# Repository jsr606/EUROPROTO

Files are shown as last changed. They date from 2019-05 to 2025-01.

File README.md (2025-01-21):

# EUROPROTO
an arduino / atmega platform for making digital eurorack modules and
various helper PCBs

based on on the [CHEAP, FAT and OPEN](https://vsionhairies.info/) synthesizer

## a what?
arduino based eurorack module with dual channel DAC output

kind of works :)

this is a prototyping platform. you can make modules that looks like this

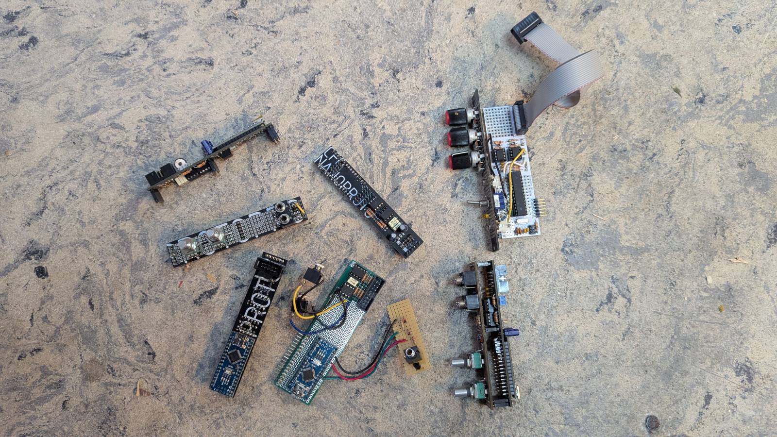
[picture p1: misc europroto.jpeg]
misc europroto.jpeg


## first version for sound days at MPLab
[workshop description and assembly guides here](/SoundDays_MPlab/README.md)

## rev3 board is here now
look in the rev3 folder. it's all old eagle stuff that i can't really open anymore, but it should possibly work?

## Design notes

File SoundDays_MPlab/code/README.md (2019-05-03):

# CFO EUROPROTO 1
# programming the module
 
the CFO EUROPROTO is based on an atmega328 chip, which is the same chip that sits at the centre of a typical arduino. this means we can program the module using the arduino software.

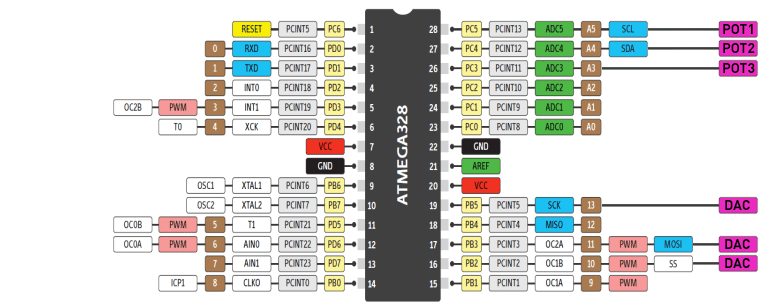
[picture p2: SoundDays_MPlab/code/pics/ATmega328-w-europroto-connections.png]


to program the module, first download the arduino IDE from https://www.arduino.cc/

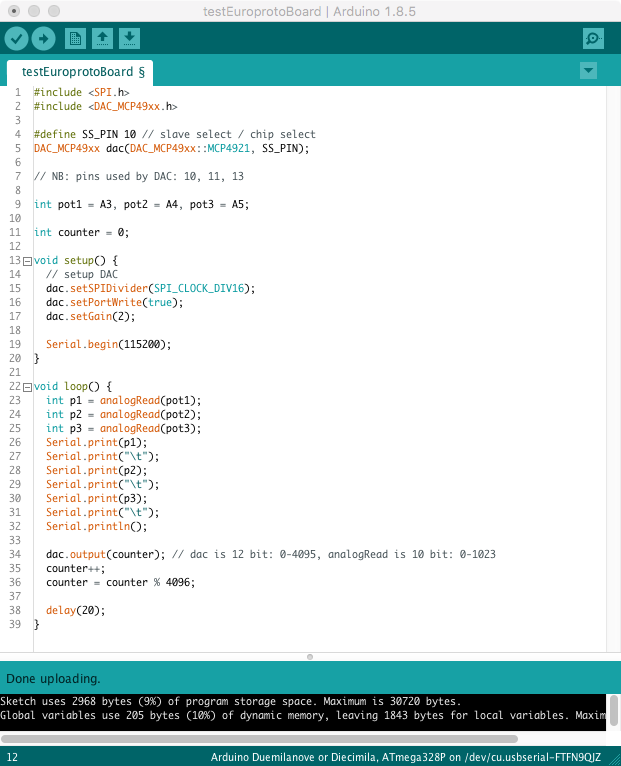
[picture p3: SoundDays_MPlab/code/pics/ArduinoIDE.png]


if you have never programmed an arduino before and need help installing the software / getting your head around microcontrollers take a look [here](https://www.arduino.cc/en/Guide/HomePage)

since the CFO EUROPROTO has no USB port, only a serial connection, you will need to use a USB to serial connecter to connect to the board.

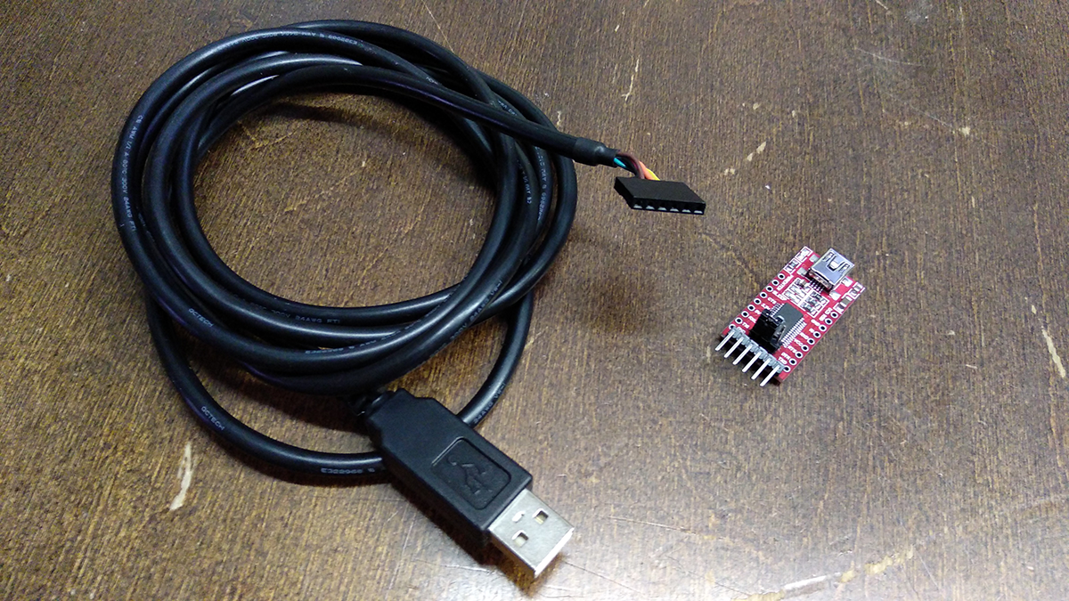
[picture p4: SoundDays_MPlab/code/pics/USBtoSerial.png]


a nice USB to serial cable [is this one](https://eu.mouser.com/ProductDetail/FTDI/TTL-234X-5V?qs=sGAEpiMZZMve4%2FbfQkoj%252BHKRsWEfBN5HUqn9pYz616g%3D), cheaper dongle style versions are [available on amazon](https://www.amazon.de/Adapter-FT232RL-Arduino-Christians-Technikshop/dp/B0178HVEH0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) too

NB: mind the orientation: GND (black wire) is down on the main board.

under tools set your arduino board to be an "arduino duemilanove and diecimila", your processor to be an "ATmega328P" and pick the USB/COM port which corresponds to you programmer (if you are unsure which it is, unplug you programmer and see which one disappears / reappears when you plug it in and out).

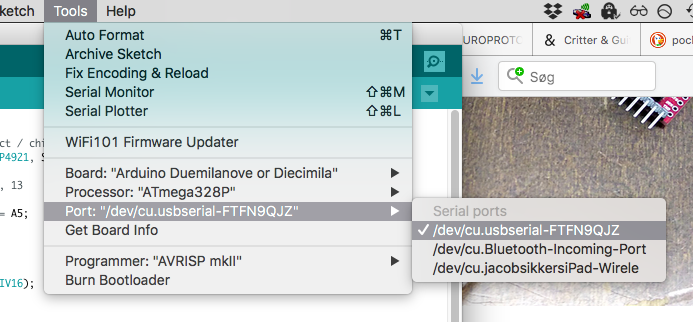
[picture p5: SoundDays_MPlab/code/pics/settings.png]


example code is in the [arduino folder](../arduino) in this repository. start with the testcode and open the serial port to see if your potentiometers are connected correctly. once this works, move on the the sound examples :)

if you would like to understand more about sound, sound synthesis, and how sound works in a computer / digital environment, i recommend reading [this processing tutorial](https://processing.org/tutorials/sound/)

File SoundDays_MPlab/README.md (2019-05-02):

# CFO EUROPROTO 1
# digital modular

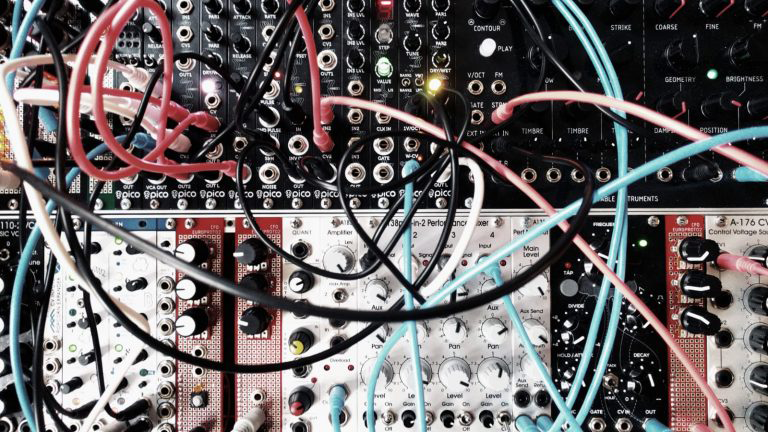
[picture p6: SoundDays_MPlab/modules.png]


workshop participants will learn to prototype simple arduino based modules that can interact with the eurorack modular world.  

programming microcontrollers in eurorack format, brings a dirty, cheap and flexible hacking approach to eurorack modular. by introducing programmable digital utility modules in the modular world we open up a pandoras box of algorithmic composition and wonderful glitches.  

the outcome of the workshop will be true hybrid modular systems that is self playing and self modulating. saturday night the workshop participants will gather for a massive common patch jam based on produced modules and doepfer a-100 system which is already available for us in mplab.  

http://sound.mplab.lv/workshops/jacob-remin/  
jacob remin, liepaja, 2-5 may 2019

## teachers

jacob remin & reinis nalivaiko

## links / references

https://vsionhairies.info/  
http://www.jacobremin.com/  
https://www.arduino.cc/  
http://sound.mplab.lv/  

## thanks!

erica synths  
https://www.ericasynths.lv/  
nordic culture point  
https://www.nordiskkulturkontakt.org  

## more infos

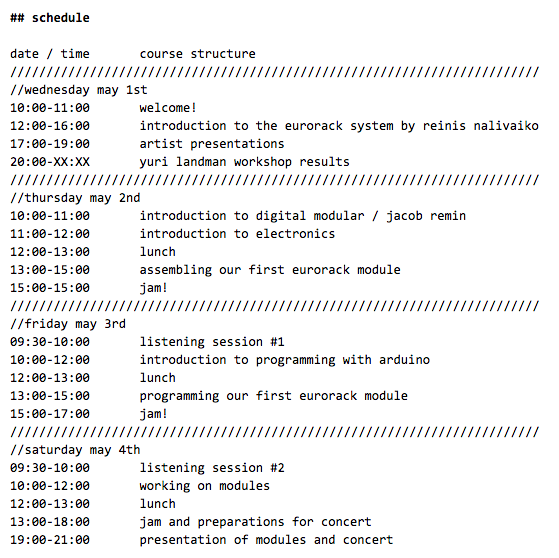
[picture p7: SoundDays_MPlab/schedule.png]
schedule
  
[build instructions](https://github.com/jsr606/EUROPROTO/tree/master/SoundDays_MPlab/build_instructions)

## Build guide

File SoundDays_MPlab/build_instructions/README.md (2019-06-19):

# CFO EUROPROTO 1
# build instructions
for digital modular workshop at MPlab sound days  
http://sound.mplab.lv/workshops/jacob-remin/  
jacob remin, liepaja, may 2019  

## BOM

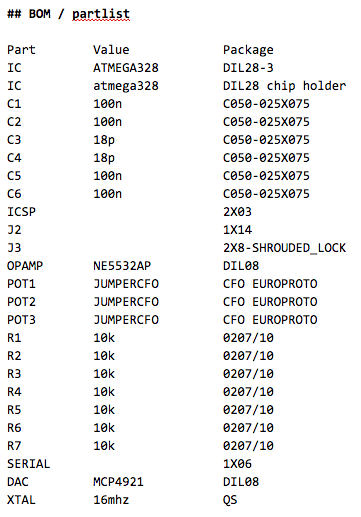
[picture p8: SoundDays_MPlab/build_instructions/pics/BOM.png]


# soldering

if you have never soldered before, i recommend looking at [this little instructional cartoon](https://blog.adafruit.com/2010/02/19/soldering-is-easy-heres-how-to-do-it-comic/)

say hello to your PCB
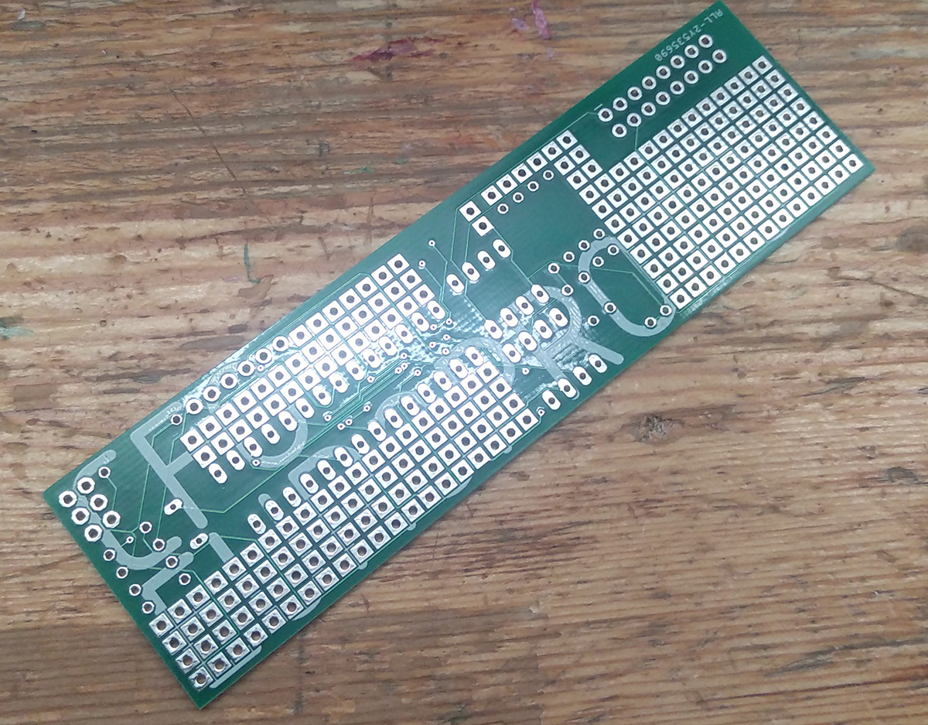
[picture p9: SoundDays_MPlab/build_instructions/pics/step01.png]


first solder the resistors. they are all 10k ohm. they have no polarity, but try to align them all the same way. just pick one. it makes it easier to see what is going on for other people (or yourself in a couple of weeeks)
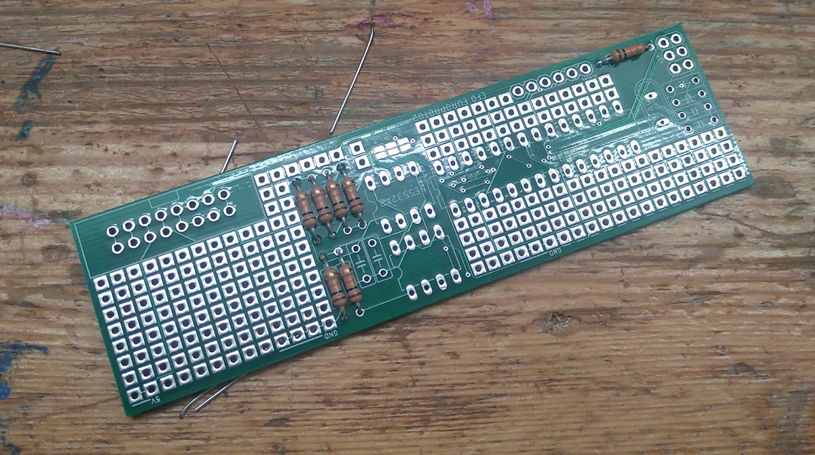
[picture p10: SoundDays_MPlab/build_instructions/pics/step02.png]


solder the 16mhz chrystal. the crystal has no polarity
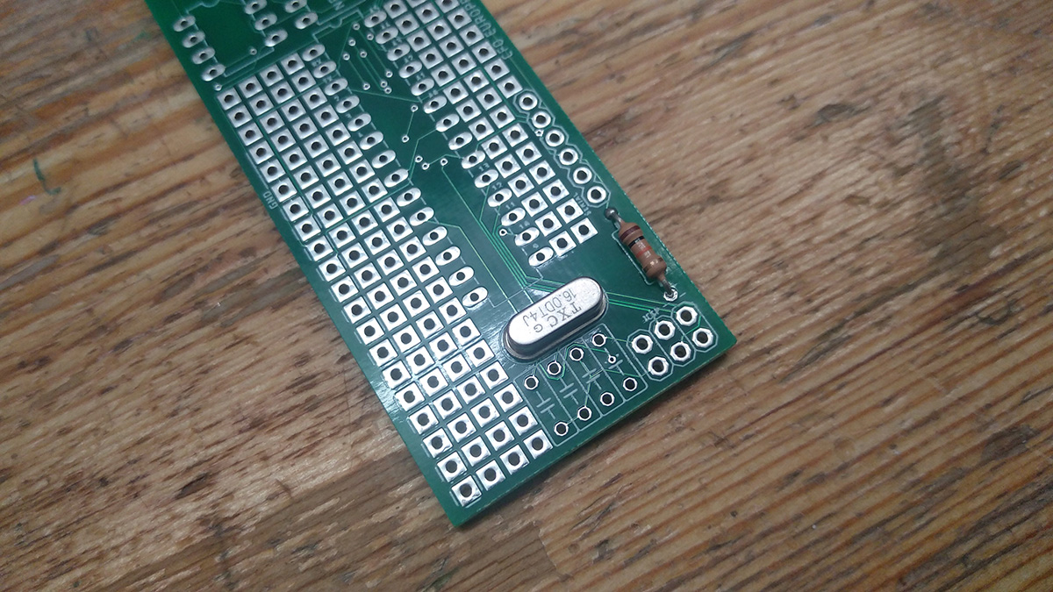
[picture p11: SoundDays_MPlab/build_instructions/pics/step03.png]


solder the 18pf capacitors. they have no polarity
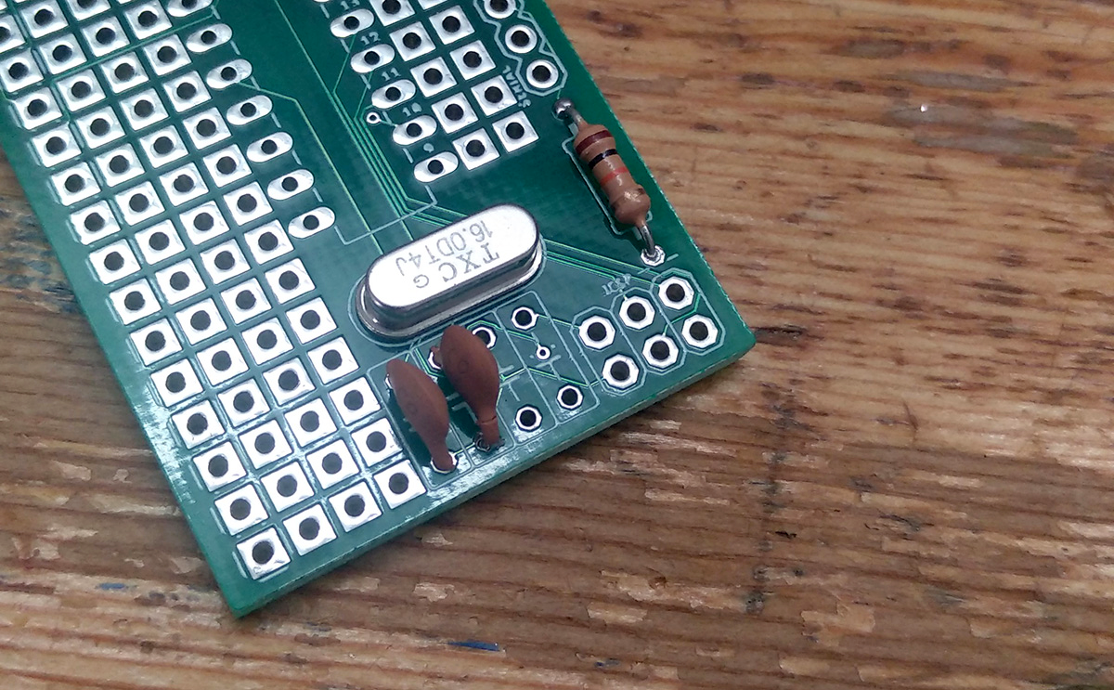
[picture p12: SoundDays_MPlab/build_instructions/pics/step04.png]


solder the 100uf capacitors. again no polarity here
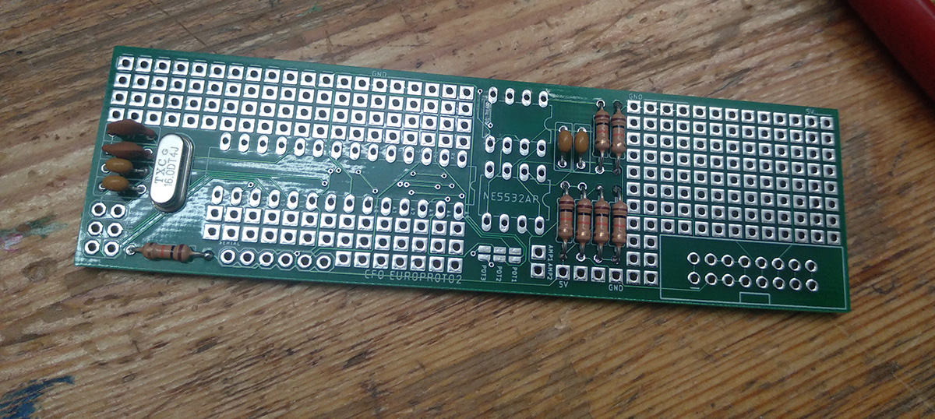
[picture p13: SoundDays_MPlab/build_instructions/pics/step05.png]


solder the IC sockets. NB: make sure to orient them correctly
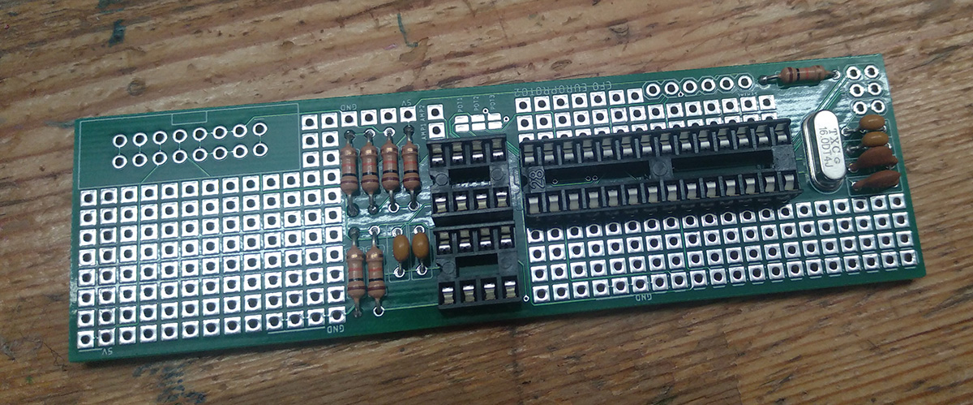
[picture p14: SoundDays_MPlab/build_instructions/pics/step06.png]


solder the programmer pin headers
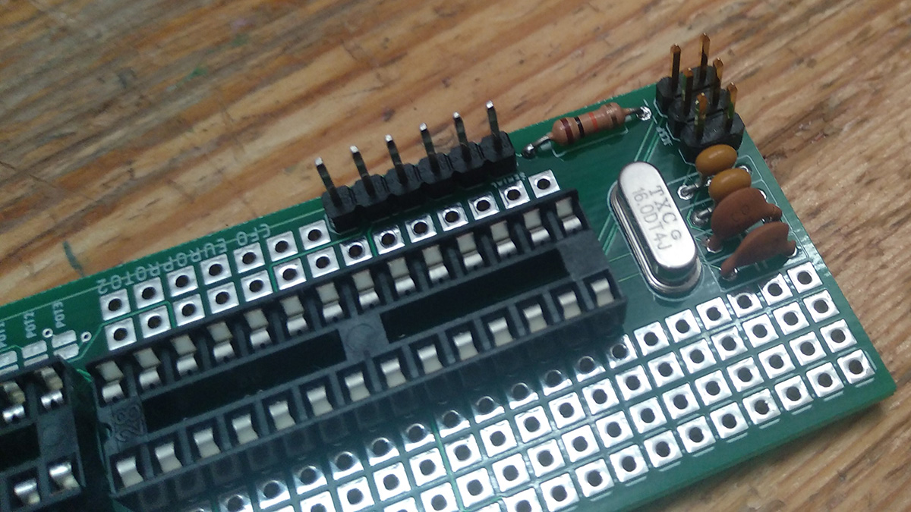
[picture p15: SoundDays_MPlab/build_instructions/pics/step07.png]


solder the power connector. for this workshop we will use 2 rows of ordinary male pin headers. to make sure they fit your eurorack power cable, connect the pin headers to the power cable while soldering them. this way they are correctly aligned
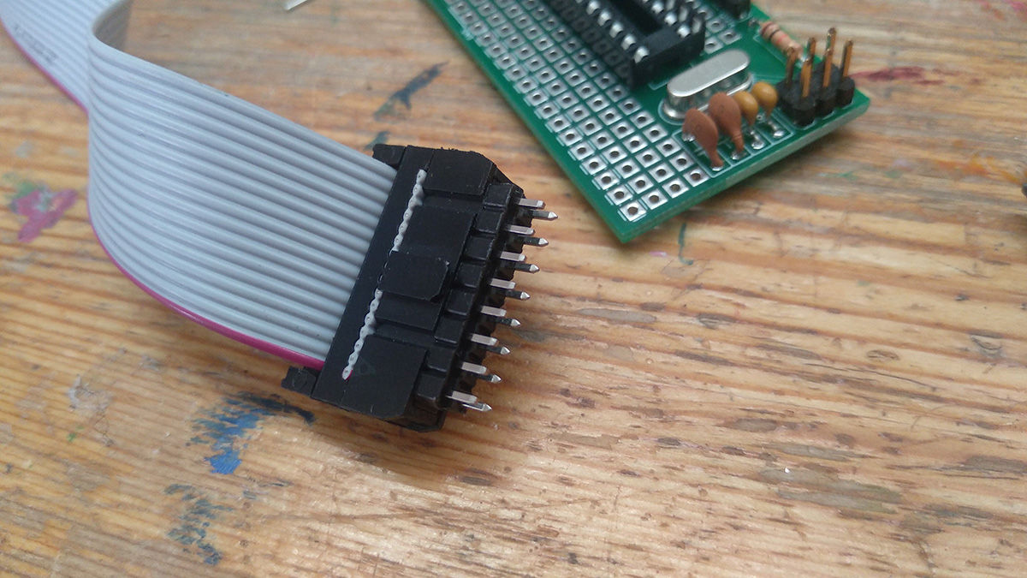
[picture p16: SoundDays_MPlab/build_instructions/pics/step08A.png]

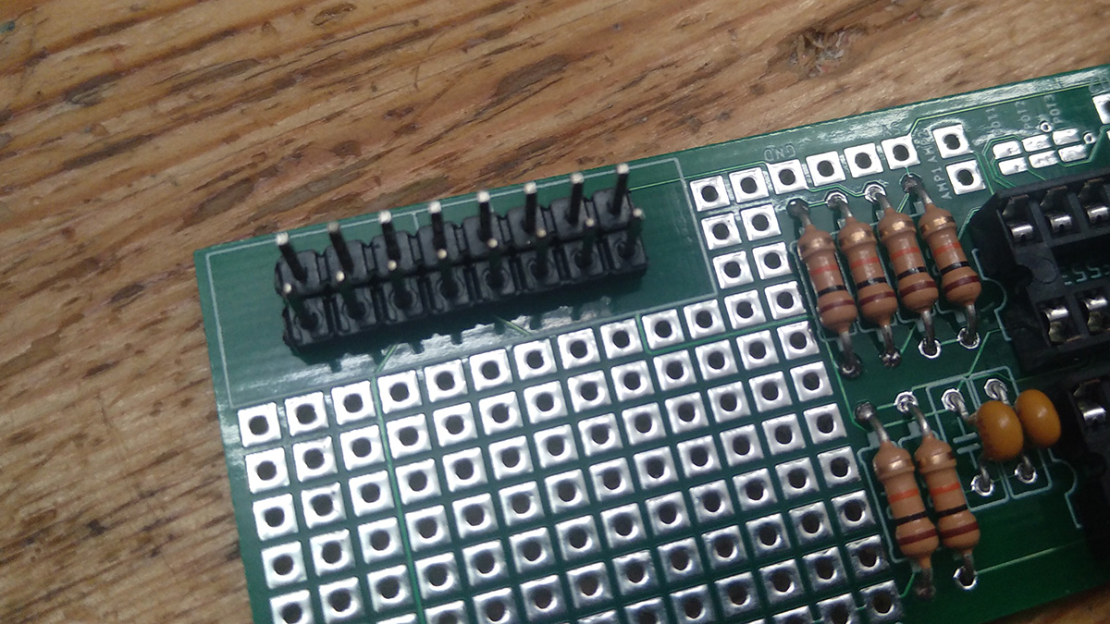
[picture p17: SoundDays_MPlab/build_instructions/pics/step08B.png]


to route the potentiometers 3 pins to the atmega328, apply solder to the 3 solder bridges marked POT1, POT2, and POT3
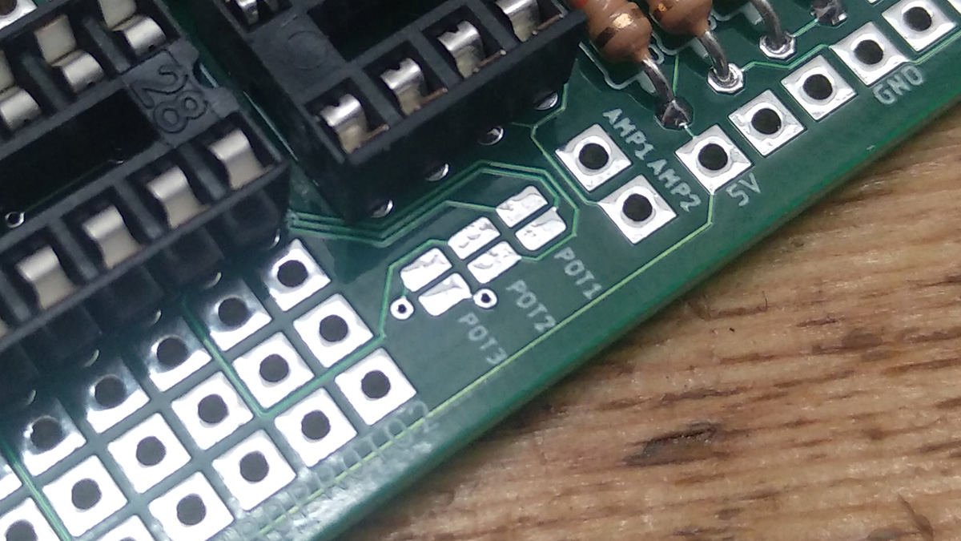
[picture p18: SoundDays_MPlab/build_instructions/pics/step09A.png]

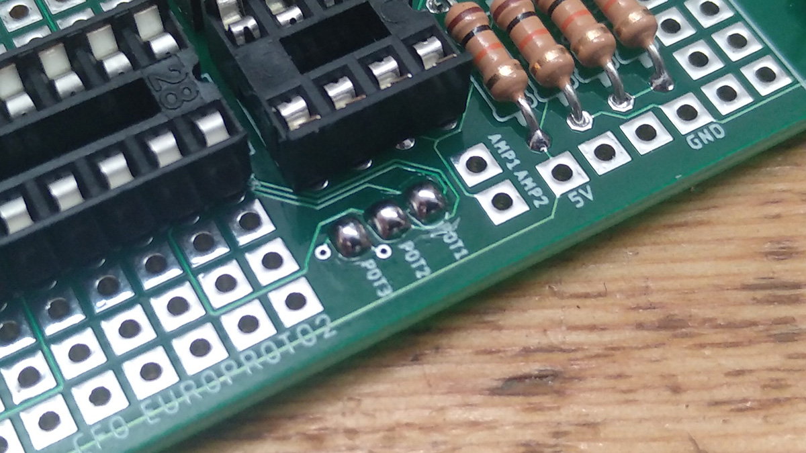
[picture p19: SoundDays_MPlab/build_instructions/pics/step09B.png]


solder the angled pin headers to the back of the PCB. NB: careful with the orientation: if you solder the pin headers to the top of the PCB your module will not fit in your synthesizer!
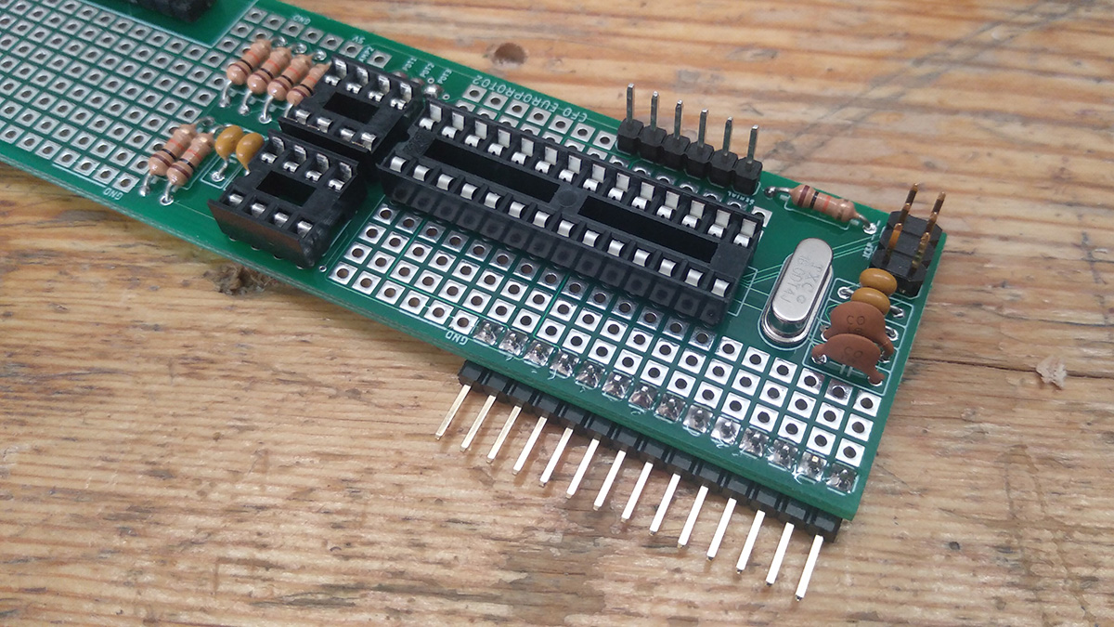
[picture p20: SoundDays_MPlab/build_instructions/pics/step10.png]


mount the ICs in the IC sockets. NB: mind the orientation of the chips, and be careful not to mix up the DAC and the opamp
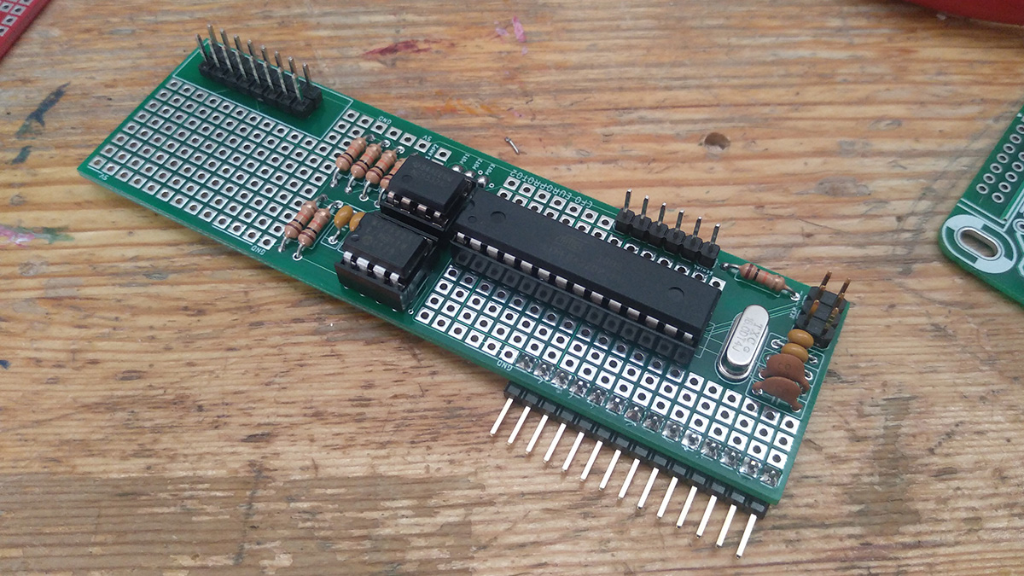
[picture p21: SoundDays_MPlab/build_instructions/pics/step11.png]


mount the ICs in the IC sockets. NB: mind the orientation of the chips, and be careful not to mix up the DAC and the opamp


that's it! you're done :) now we need to add a faceplate and program it

# faceplate

now it gets interesting! you have to decide on how many plugs your module needs. if in doubt, i suggest 3 plugs.

mark on the PCB where you want to position the plugs and drill holes :) NB: make sure you can fit the plugs and the electronics on the backside, when you solder faceplate and mainboard together. see pics below for suggested placement:

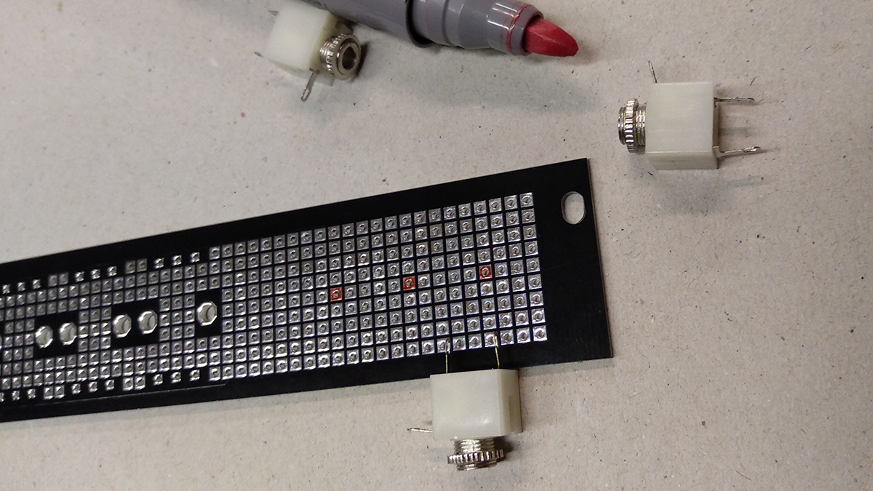
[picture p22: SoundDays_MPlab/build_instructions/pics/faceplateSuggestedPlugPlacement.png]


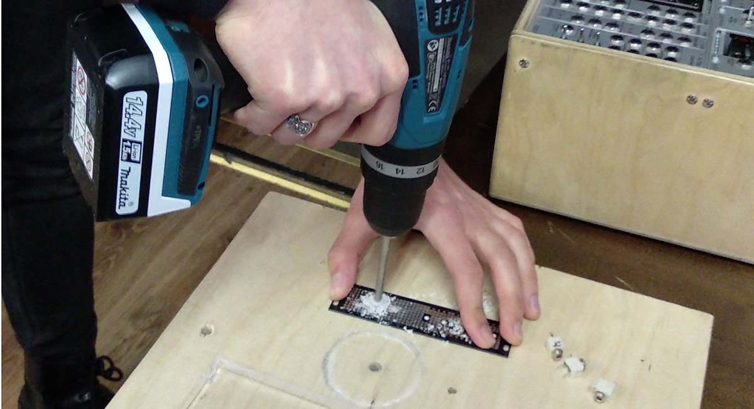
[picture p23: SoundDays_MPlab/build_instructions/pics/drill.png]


once you have the plugs mounted on the faceplate it's time to solder the potentiometers.

when connecting the faceplate to the mainboard be sure everything is aligned in a perfect 90 degree angle: solder one or two pins and calibrate before soldering all the pins. NB: if things are not straight, you module might not fit in inside your synthesizer!

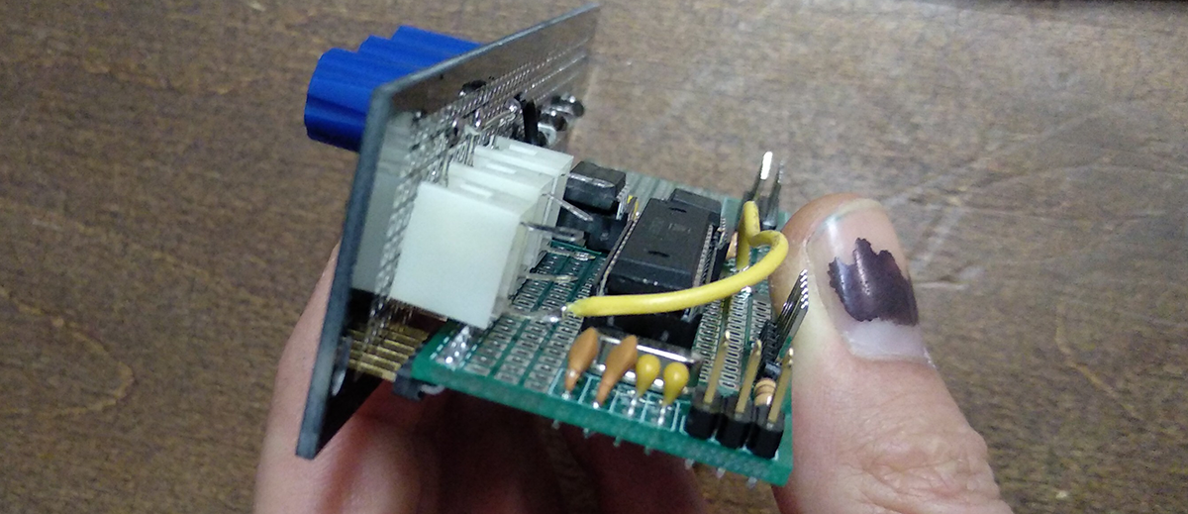
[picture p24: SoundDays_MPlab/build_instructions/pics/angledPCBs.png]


connect the ground pins of the audio jacks together. you can use wire, but might as well use some of the cut off legs from used components that you have floating around your work desk by now. 

then wire the jacks to GND on the mainboard.

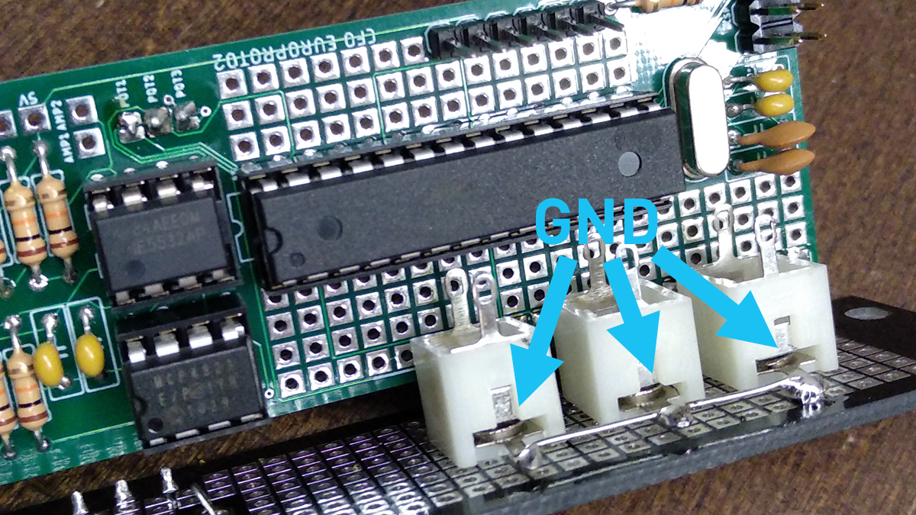
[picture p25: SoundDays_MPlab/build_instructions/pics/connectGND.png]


GND from the jacks to GND on the mainboard (could be anywhere, but see suggested connector on pic), and connect AMP1 to tip connector of the audio / CV out jack (see pic).

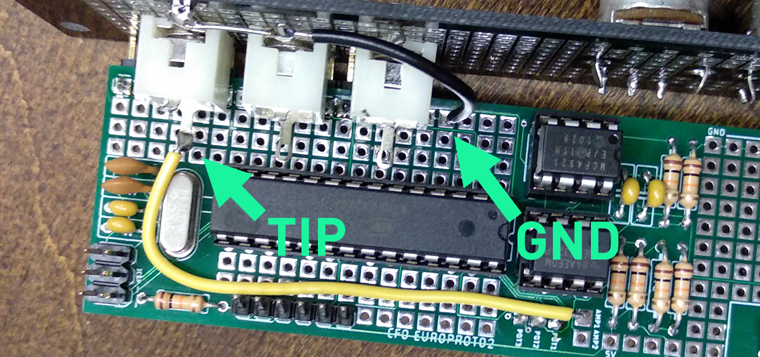
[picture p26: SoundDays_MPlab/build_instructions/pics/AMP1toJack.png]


now attach knobs to your potentiometers, and hey: well done! you've assembled your first module :)

once the module is assembled, we need to upload testcode to the chip to see if everything works. go to the [code](https://github.com/jsr606/EUROPROTO/tree/master/SoundDays_MPlab/code) part of this repository to find code examples and guidelines

# notes on output and amplification

the CFO europroto works by using a 12-bit DAC to create an analog signal between 0 and 5V (2 signals if you choose the MCP4822 DAC over the MCP4921)
this signal is the amplified to the range of -5V to 5V or 0V to 10V using the NE5532 op amp. selection between the two voltage ranges are made by applying solder to the two solder jumpers named "amp1" and "amp2". by soldering the middle pad to pad 1 a range of 0V to 10V output is selected (typical for CV applications), by soldering the middle pad to pad 2 a range of -5V to 5V is selected (typical for audio applications).

a simulation of the -5V to 5V op amp circuit can be found here: http://tinyurl.com/y3vhav76

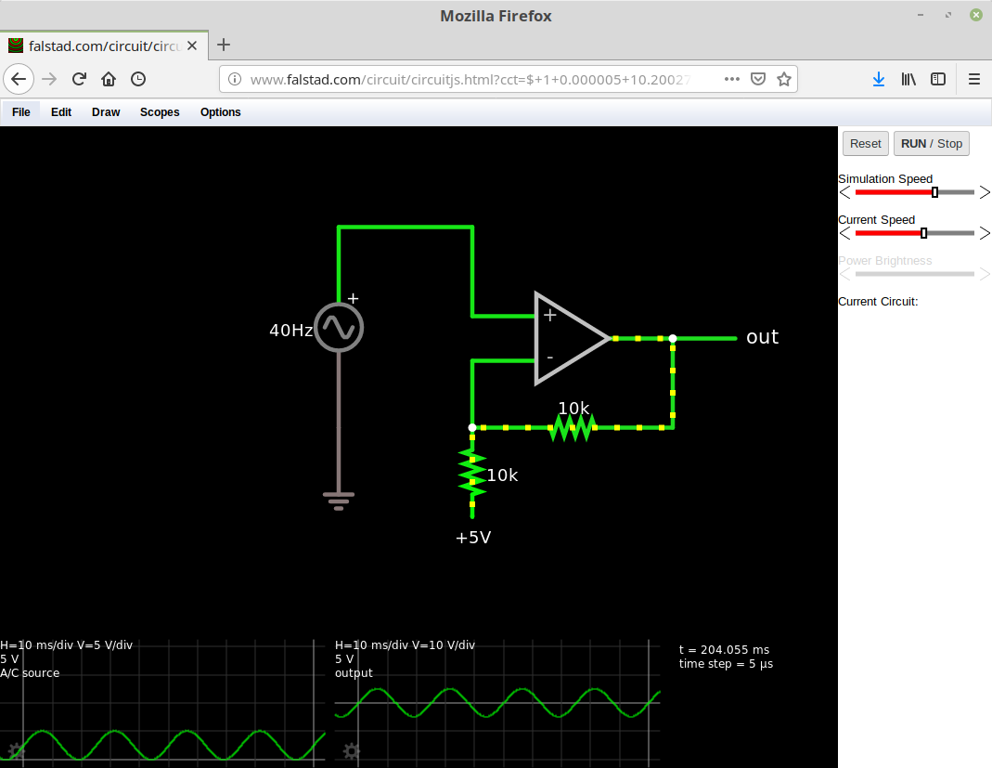
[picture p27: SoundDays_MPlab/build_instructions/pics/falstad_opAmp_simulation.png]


a simulation of the 0V to 10V op amp circuit can be found here: http://tinyurl.com/yxrvrr4l

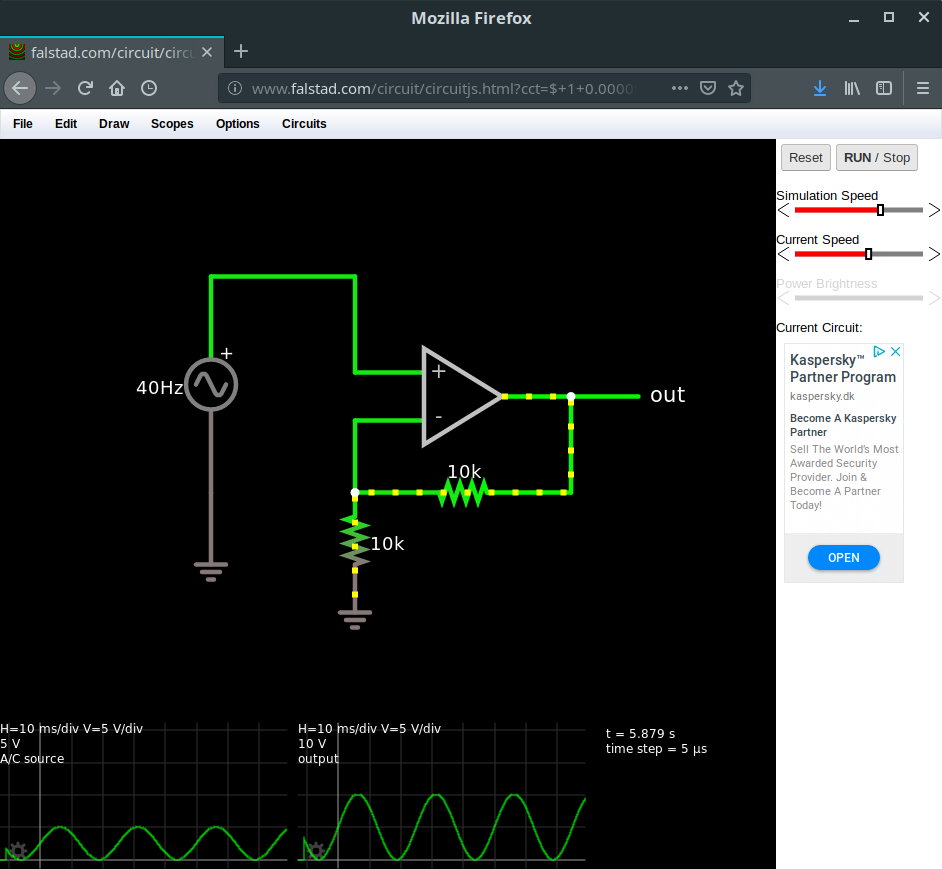
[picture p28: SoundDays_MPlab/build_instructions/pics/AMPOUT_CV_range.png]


if you are using the 1 channel DAC (MCP4921), you need to apply reference current on the VREF input of the DAC. this is conveiniently done so by soldering the solder bridge marked "VREF5V" together. if you are using the 2 channel DAC (MCP4822), the chip has internal VREF and you do NOT solder this solder bridge together.

# expansion possibilities

the following is small schematics for possible expansions, giving your module more capabilities

## CV in

use the following schematic to scale voltages from -10V to 10V to an atmega safe 0 to 5V
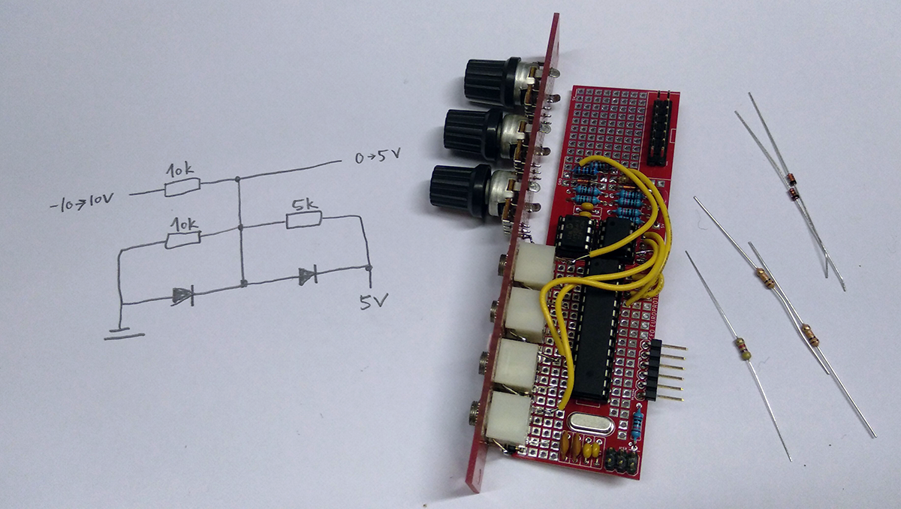
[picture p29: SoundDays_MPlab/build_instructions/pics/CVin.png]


a simulation of the CV input scaling circuit can be found here: http://tinyurl.com/y2xc58qk

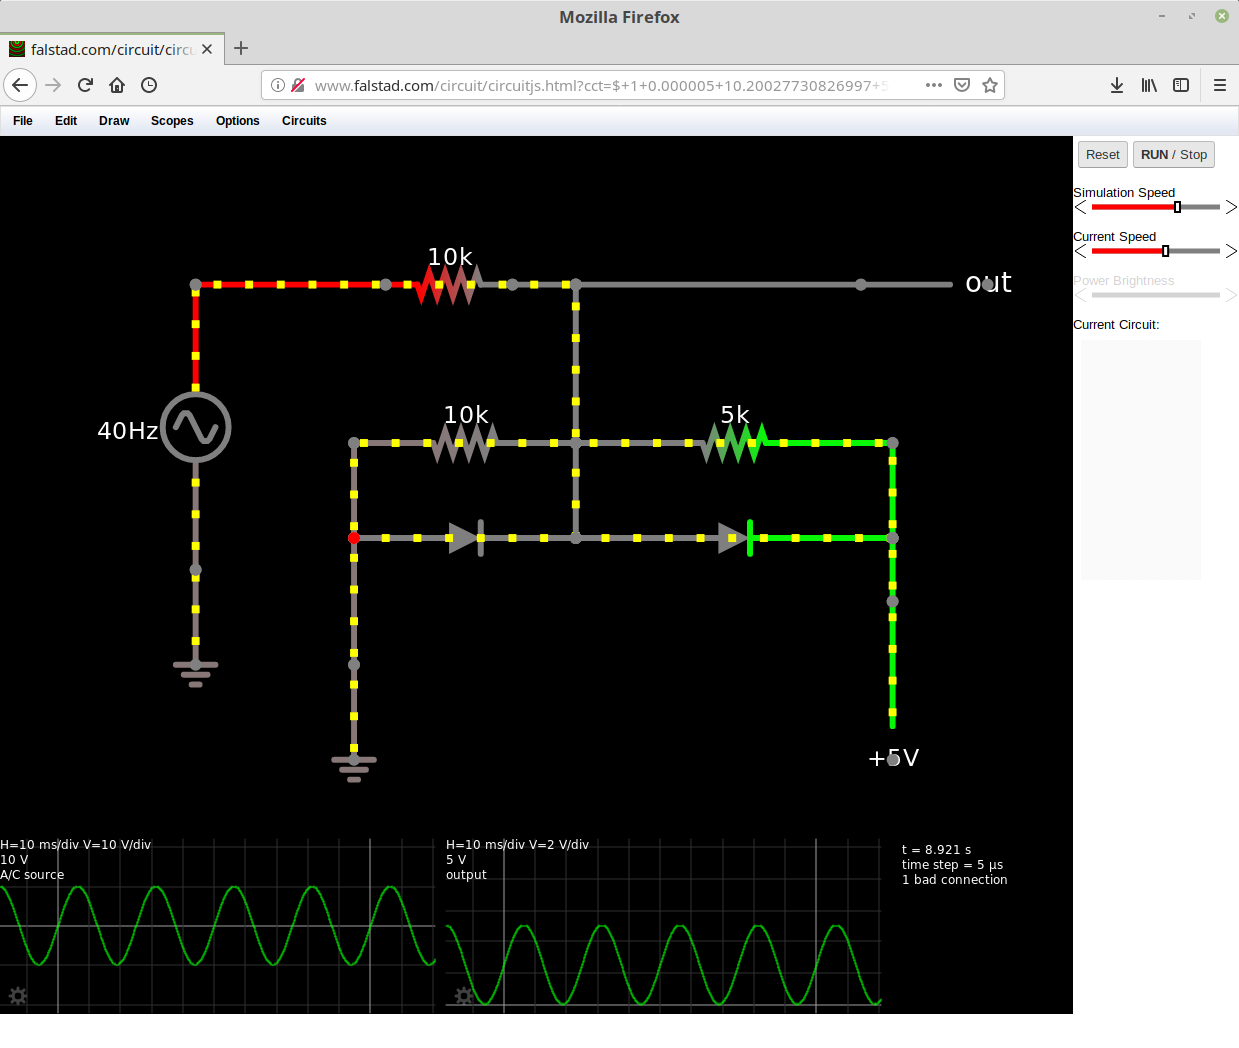
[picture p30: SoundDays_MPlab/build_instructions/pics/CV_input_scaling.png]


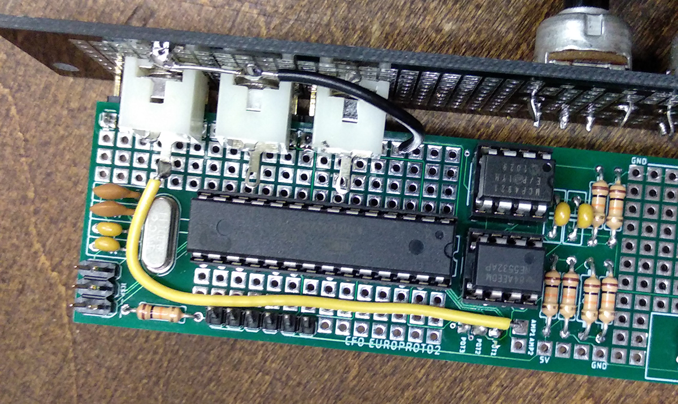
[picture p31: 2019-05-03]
SoundDays_MPlab/build_instructions/pics/GNDandAMP.png

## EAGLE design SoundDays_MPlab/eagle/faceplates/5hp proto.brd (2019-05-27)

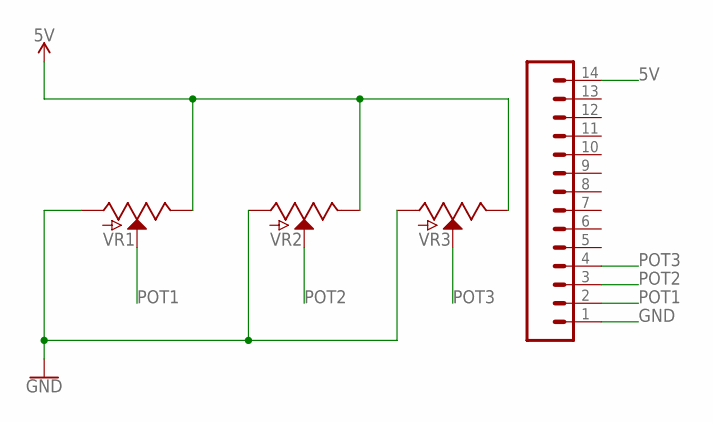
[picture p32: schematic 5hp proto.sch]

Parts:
J2: CONN_14SQUARE; 1X14
VR1, VR2, VR3: POTENTIOMETERPOTV; POT_V

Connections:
5V: J2.14, VR1.P3 (E), VR2.P3 (E), VR3.P3 (E)
GND: J2.1, VR1.P1 (A), VR2.P1 (A), VR3.P1 (A)
POT1: J2.2, VR1.P2 (S)
POT2: J2.3, VR2.P2 (S)
POT3: J2.4, VR3.P2 (S)

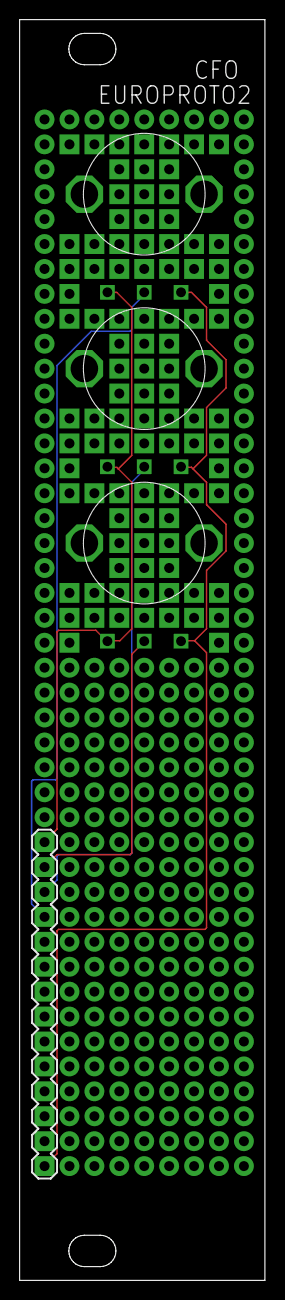
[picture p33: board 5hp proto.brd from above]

Board: 2 copper layers, 25.0 x 128.5 mm, 4 parts (0 on the bottom side), 5 nets.

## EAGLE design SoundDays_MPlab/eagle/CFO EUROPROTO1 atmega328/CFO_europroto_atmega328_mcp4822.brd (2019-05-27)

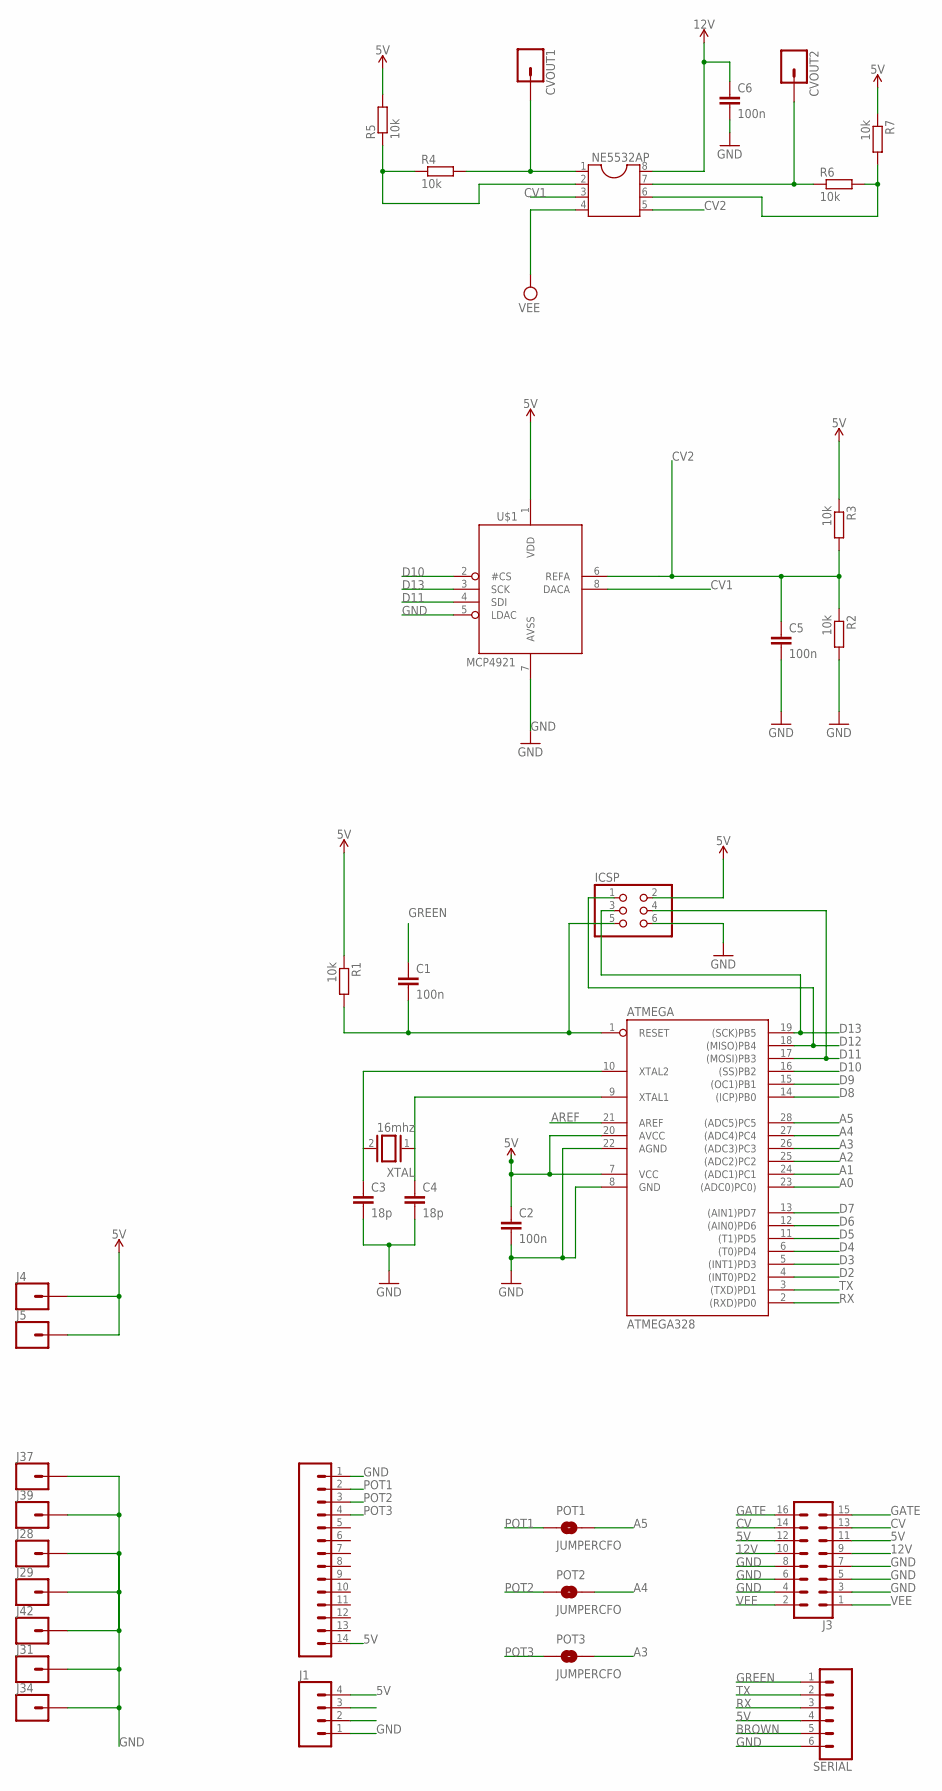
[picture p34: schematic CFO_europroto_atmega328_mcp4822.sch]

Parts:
ATMEGA: ATMEGA328; DIL28-3
C1, C2, C5, C6: 100n; C050-025X075
C3, C4: 18p; C050-025X075
CVOUT1, CVOUT2: CONN_01; 1X01
ICSP: PINHD-2X3; 2X03
J1: CONN_04; 1X04
J2: CONN_14SQUARE; 1X14
J3: CONN_08X2_SHROUD; 2X8-SHROUDED_LOCK
J4, J5, J28, J29, J31, J34, J37, J39, J42: CONN_01; 1X01
NE5532AP: DIL8; DIL08
POT1, POT2, POT3: JUMPERCFO; SMT-JUMPER_2_NO_NO-SILK_ROUND
R1, R2, R3, R4, R5, R6, R7: 10k; 0207/10
SERIAL: CONN_06SILK_FEMALE_PTH; 1X06
U$1: MCP4921; DIL08
XTAL: 16mhz; QS

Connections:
5V: ATMEGA.7 (VCC), ATMEGA.20 (AVCC), C2.1, ICSP.2, J1.4, J2.14, J3.11, J3.12, J4.1, J5.1, R1.1, R3.1, R5.2, R7.1, SERIAL.4, U$1.1 (VDD)
12V: C6.1, J3.9, J3.10, NE5532AP.8
A0: ATMEGA.23 ((ADC0)PC0))
A1: ATMEGA.24 ((ADC1)PC1)
A2: ATMEGA.25 ((ADC2)PC2)
A3: ATMEGA.26 ((ADC3)PC3), POT3.2
A4: ATMEGA.27 ((ADC4)PC4), POT2.2
A5: ATMEGA.28 ((ADC5)PC5), POT1.2
AREF: ATMEGA.21 (AREF)
BROWN: SERIAL.5
CV: J3.13, J3.14
CV1: NE5532AP.3, U$1.8 (DACA)
CV2: C5.1, NE5532AP.5, R2.1, R3.2, U$1.6 (REFA)
CVOUT1: CVOUT1.1, NE5532AP.1, R4.2
CVOUT2: CVOUT2.1, NE5532AP.7, R6.1
D2: ATMEGA.4 ((INT0)PD2)
D3: ATMEGA.5 ((INT1)PD3)
D4: ATMEGA.6 ((T0)PD4)
D5: ATMEGA.11 ((T1)PD5)
D6: ATMEGA.12 ((AIN0)PD6)
D7: ATMEGA.13 ((AIN1)PD7)
D8: ATMEGA.14 ((ICP)PB0)
D9: ATMEGA.15 ((OC1)PB1)
D10: ATMEGA.16 ((SS)PB2), U$1.2 (#CS)
D11: ATMEGA.17 ((MOSI)PB3), ICSP.4, U$1.4 (SDI)
D12: ATMEGA.18 ((MISO)PB4), ICSP.1
D13: ATMEGA.19 ((SCK)PB5), ICSP.3, U$1.3 (SCK)
GATE: J3.15, J3.16
GND: ATMEGA.8 (GND), ATMEGA.22 (AGND), C2.2, C3.2, C4.2, C5.2, C6.2, ICSP.6, J1.1, J2.1, J3.3, J3.4, J3.5, J3.6, J3.7, J3.8, J28.1, J29.1, J31.1, J34.1, J37.1, J39.1, J42.1, R2.2, SERIAL.6, U$1.5 (LDAC), U$1.7 (AVSS)
GREEN: C1.1, SERIAL.1
unnamed: ATMEGA.10 (XTAL2), C3.1, XTAL.2
unnamed: NE5532AP.6, R6.2, R7.2
unnamed: NE5532AP.2, R4.1, R5.1
unnamed: ATMEGA.9 (XTAL1), C4.1, XTAL.1
POT1: J2.2, POT1.1
POT2: J2.3, POT2.1
POT3: J2.4, POT3.1
RESET: ATMEGA.1 (RESET), C1.2, ICSP.5, R1.2
RX: ATMEGA.2 ((RXD)PD0), SERIAL.3
TX: ATMEGA.3 ((TXD)PD1), SERIAL.2
VEE: J3.1, J3.2, NE5532AP.4

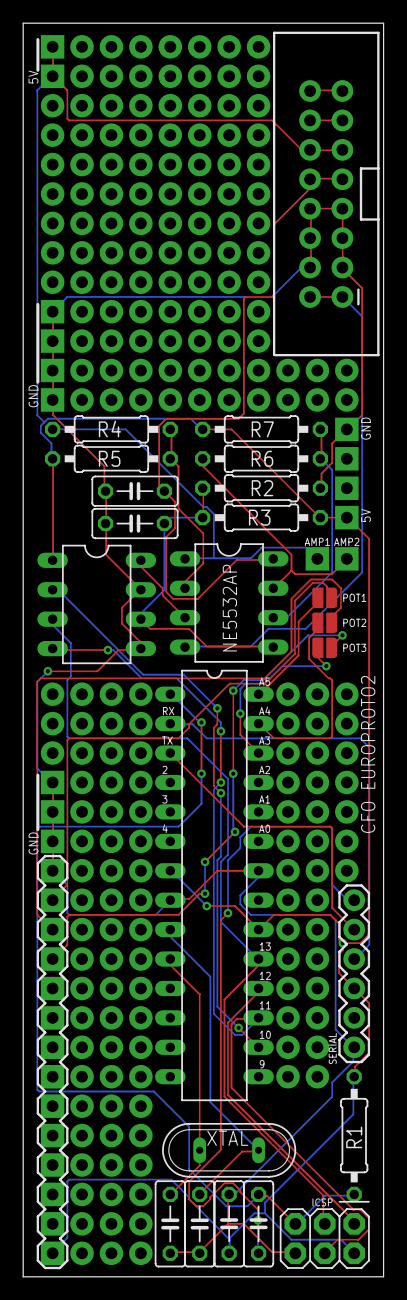
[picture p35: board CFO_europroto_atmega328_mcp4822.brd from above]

Board: 2 copper layers, 31.1 x 108.2 mm, 36 parts (0 on the bottom side), 28 nets.

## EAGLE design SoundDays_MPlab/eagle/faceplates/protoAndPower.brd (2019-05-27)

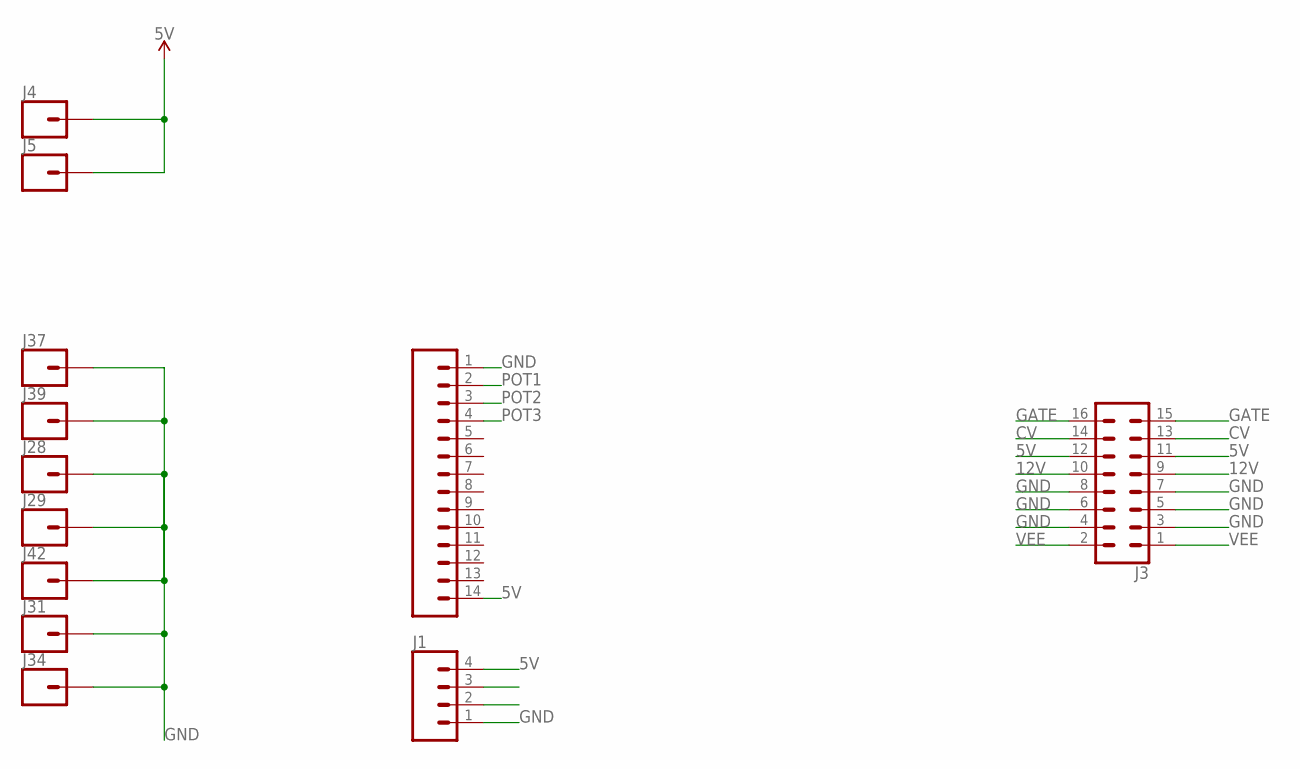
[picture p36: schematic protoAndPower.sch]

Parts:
J1: CONN_04; 1X04
J2: CONN_14SQUARE; 1X14
J3: CONN_08X2_SHROUD; 2X8-SHROUDED_LOCK
J4, J5, J28, J29, J31, J34, J37, J39, J42: CONN_01; 1X01

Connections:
5V: J1.4, J2.14, J3.11, J3.12, J4.1, J5.1
12V: J3.9, J3.10
CV: J3.13, J3.14
GATE: J3.15, J3.16
GND: J1.1, J2.1, J3.3, J3.4, J3.5, J3.6, J3.7, J3.8, J28.1, J29.1, J31.1, J34.1, J37.1, J39.1, J42.1
POT1: J2.2
POT2: J2.3
POT3: J2.4
VEE: J3.1, J3.2

Board: 2 copper layers, 12 parts (0 on the bottom side), 6 nets, no tracks yet.

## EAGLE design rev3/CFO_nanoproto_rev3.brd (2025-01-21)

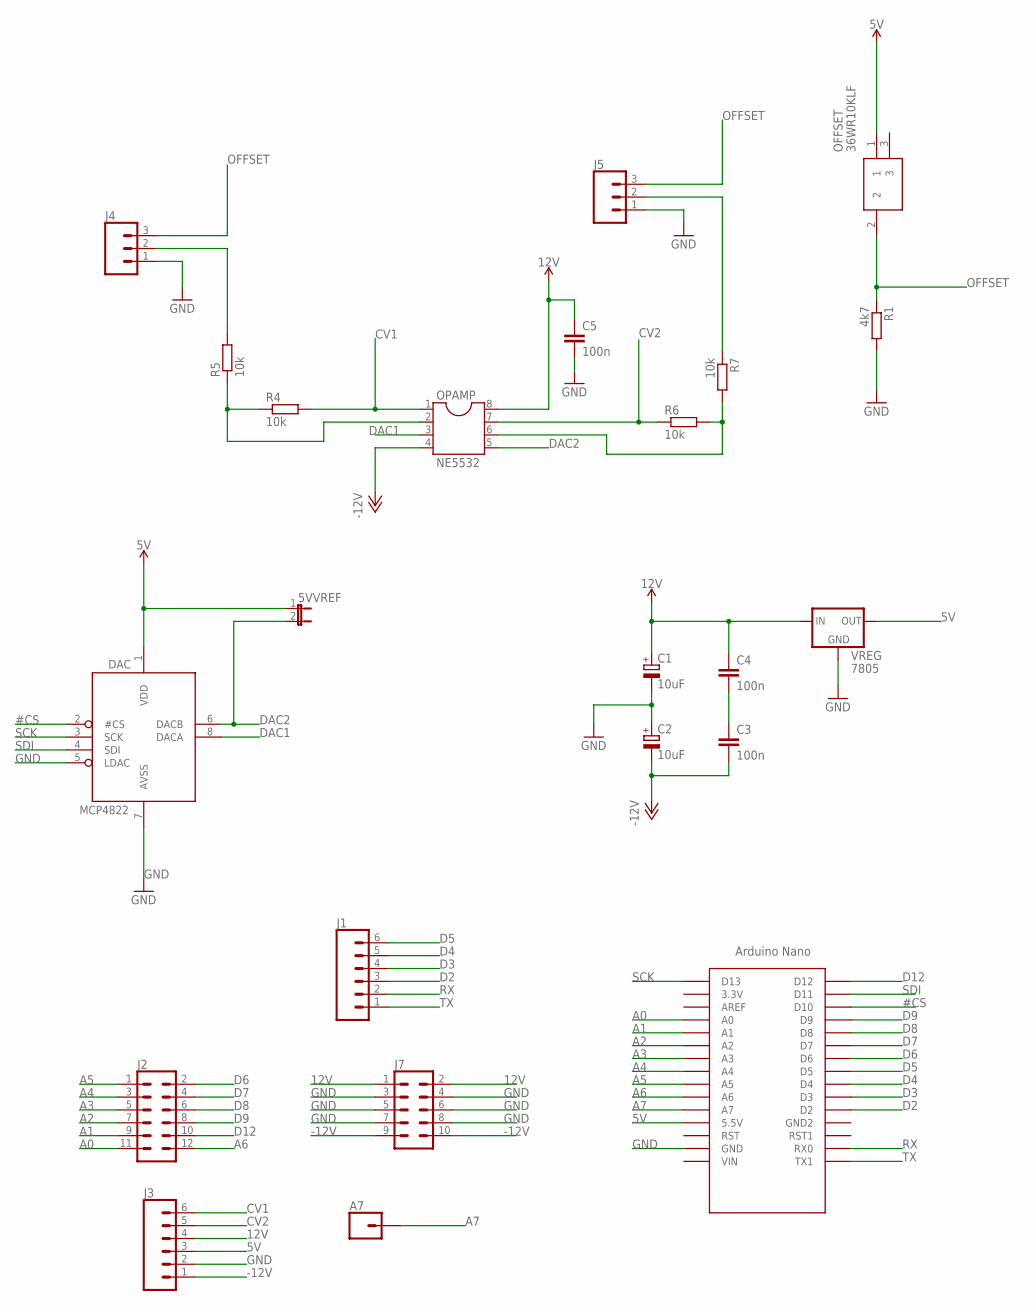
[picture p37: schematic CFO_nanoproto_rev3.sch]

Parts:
5VVREF: JUMPER-2PTH; 1X02
A7: CONN_01; 1X01
C1, C2: 10uF; E2-5
C3, C4, C5: 100n; C050-025X075
DAC: MCP4822; DIL08
J1, J3: CONN_06NO_SILK_NO_POP; 1X06_NO_SILK
J2: 2X6 FEMALE; 2X6
J4, J5: CONN_03; 1X03
J7: EURO_CONN_05X2SHD; 2X5-SHROUDED
OFFSET: 36WR10KLF
OPAMP: NE5532; DIL08
R1: 4k7; 0207/10
R4, R5, R6, R7: 10k; 0207/10
U$2: NANO
VREG: 7805; 78XXL_NOHOLE

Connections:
5V: 5VVREF.1, DAC.1 (VDD), J3.3, OFFSET.1, U$2.5V (5.5V), VREG.OUT
12V: C1.+, C4.1, C5.1, J3.4, J7.1, J7.2, OPAMP.8, VREG.IN
#CS: DAC.2 (#CS), U$2.D10
-12V: C2.-, C3.2, J3.1, J7.9, J7.10, OPAMP.4
A0: J2.11, U$2.A0
A1: J2.9, U$2.A1
A2: J2.7, U$2.A2
A3: J2.5, U$2.A3
A4: J2.3, U$2.A4
A5: J2.1, U$2.A5
A6: J2.12, U$2.A6
A7: A7.1, U$2.A7
CV1: J3.6, OPAMP.1, R4.2
CV2: J3.5, OPAMP.7, R6.1
D2: J1.3, U$2.D2
D3: J1.4, U$2.D3
D4: J1.5, U$2.D4
D5: J1.6, U$2.D5
D6: J2.2, U$2.D6
D7: J2.4, U$2.D7
D8: J2.6, U$2.D8
D9: J2.8, U$2.D9
D12: J2.10, U$2.D12
DAC1: DAC.8 (DACA), OPAMP.3
DAC2: 5VVREF.2, DAC.6 (DACB), OPAMP.5
GND: C1.-, C2.+, C5.2, DAC.5 (LDAC), DAC.7 (AVSS), J3.2, J4.1, J5.1, J7.3, J7.4, J7.5, J7.6, J7.7, J7.8, R1.2, U$2.GND, VREG.GND
unnamed: C3.1, C4.2
unnamed: OPAMP.6, R6.2, R7.2
unnamed: J4.2, R5.2
unnamed: OPAMP.2, R4.1, R5.1
unnamed: J5.2, R7.1
OFFSET: J4.3, J5.3, OFFSET.2, R1.1
RX: J1.2, U$2.RX0
SCK: DAC.3 (SCK), U$2.D13
SDI: DAC.4 (SDI), U$2.D11
TX: J1.1, U$2.TX1

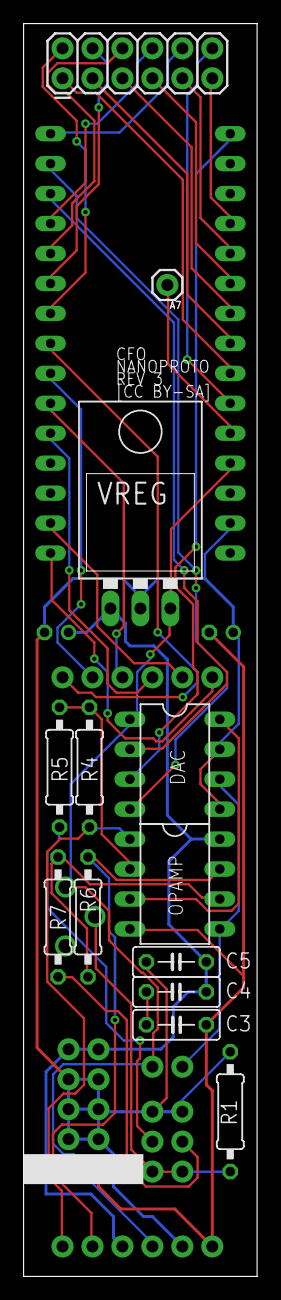
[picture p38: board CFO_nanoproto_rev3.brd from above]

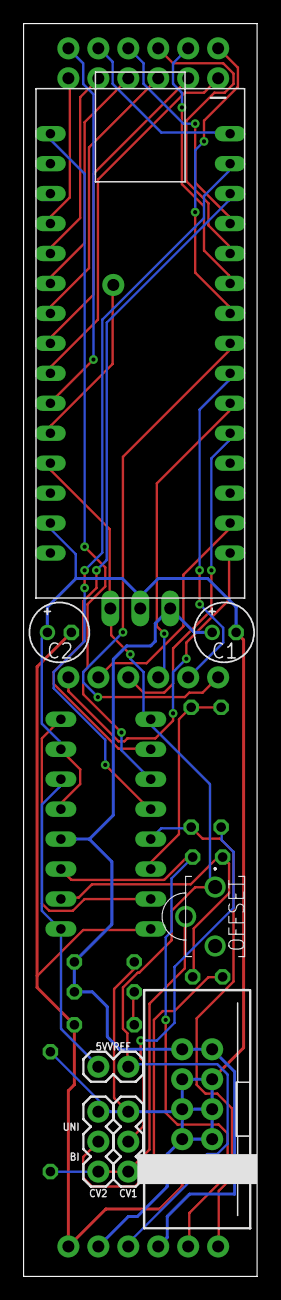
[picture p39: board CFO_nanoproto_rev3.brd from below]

Board: 2 copper layers, 19.8 x 106.2 mm, 23 parts (8 on the bottom side), 36 nets.

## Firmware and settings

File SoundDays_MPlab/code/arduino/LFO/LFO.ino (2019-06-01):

#include <SPI.h>
#include <DAC_MCP49xx.h>
#define SS_PIN 10 // slave select / chip select
DAC_MCP49xx dac(DAC_MCP49xx::MCP4921, SS_PIN);

// NB: pins used by DAC: 10, 11, 13

int pot1 = A3, pot2 = A4, pot3 = A5;
float counter = 0;

void setup() {
  // setup DAC
  dac.setSPIDivider(SPI_CLOCK_DIV16);
  dac.setPortWrite(true);
  dac.setGain(2);

  Serial.begin(115200);
}

void loop() {
  int p1 = analogRead(pot1);
  int p2 = analogRead(pot2);
  int p3 = analogRead(pot3);

  p1 = 50;

  float increment = (p1 + 1) / 500.0;     // dividing by 500.0 forces result to be float
  counter = counter + increment;
  
  if (counter > 360) counter = 0;

  float sinVal = sin(radians(counter));   // sin reads radians and returns value from -1 to 1
  int lfoVal = (sinVal + 1) * 2048;       // add 1 and multiply by 2048 to fit 12 bit DAC output range of 0-4096
  dac.output(lfoVal);
  //printPots();
  Serial.println(lfoVal);

  delay(1);
}

void printPots() {
  int p1 = analogRead(pot1);
  int p2 = analogRead(pot2);
  int p3 = analogRead(pot3);

  Serial.print(p1);
  Serial.print("\t");
  Serial.print(p2);
  Serial.print("\t");
  Serial.print(p3);
  Serial.println();
}

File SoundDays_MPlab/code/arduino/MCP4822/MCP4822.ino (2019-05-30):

#include <SPI.h>
 
const int PIN_CS = 10;
const int GAIN_1 = 0x1;
const int GAIN_2 = 0x0;
 
void setup()
{
  pinMode(PIN_CS, OUTPUT);
  SPI.begin();  
  SPI.setClockDivider(SPI_CLOCK_DIV2);
}

 
void loop()
{
 for (int i=0; i < 4096; i++)   
 {
  setOutput(0, GAIN_2, 1, i);
  setOutput(1, GAIN_2, 1, 4095-i);
  delay(1);
 }
}

void setOutput(unsigned int val)
{
  byte lowByte = val & 0xff;
  byte highByte = ((val >> 8) & 0xff) | 0x10;
   
  PORTB &= 0xfb;
  SPI.transfer(highByte);
  SPI.transfer(lowByte);
  PORTB |= 0x4;
}
 
void setOutput(byte channel, byte gain, byte shutdown, unsigned int val)
{
  byte lowByte = val & 0xff;
  byte highByte = ((val >> 8) & 0xff) | channel << 7 | gain << 5 | shutdown << 4;
   
  PORTB &= 0xfb;
  SPI.transfer(highByte);
  SPI.transfer(lowByte);
  PORTB |= 0x4;
}

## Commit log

2019-05-02 BOM / schedule
2019-05-03 arduino and programmers
2019-05-06 Oscillator with CV Input
    An oscillator with CV Input written during Sound Days.
    [Wavetable.ino, pecussiveOscillator_CVtoGain.ino]
2019-05-27 added eagle files
    [3hp.brd, 3hp.sch, 4hp proto.brd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]
2019-05-27 added schematic screenshot from eagle
    [CFO_europroto_atmega328_mcp4822.brd, CFO_europroto_atmega328_mcp4822.sch, CFO_nano_protoWithDACandOpAmpMCP4822.brd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]
2019-06-01 added op amp circuit simulation
2019-06-05 alternative op amp circuit
2019-06-19 fix vref level on mcp4921 and added possibility of CV range toggle
    [CFO_europroto_vref_CVrange.GBL, CFO_europroto_vref_CVrange.GBO, CFO_europroto_vref_CVrange.GBP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]
2025-01-21 added rev3
    [3hp.brd, 3hp.sch, 4hp proto.brd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]

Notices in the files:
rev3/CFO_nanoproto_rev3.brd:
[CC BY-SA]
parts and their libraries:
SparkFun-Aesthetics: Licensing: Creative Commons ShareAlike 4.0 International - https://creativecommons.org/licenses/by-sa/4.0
